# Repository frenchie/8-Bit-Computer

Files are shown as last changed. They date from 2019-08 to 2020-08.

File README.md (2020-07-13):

# An 8-bit Computer

My take on breadboard computer designs from [Ben Eater](https://eater.net/8bit) ([YouTube](https://www.youtube.com/channel/UCS0N5baNlQWJCUrhCEo8WlA)) and [James Bates](https://github.com/jamesbates/jcpu) ([YouTube](https://www.youtube.com/channel/UCH09NwwJsfThwLKvc6kxl4Q)).

## Licensing

* The AVR Code for the 7-segment display driver, ALU & Clock are available to use under a MIT license
* The Microcode generator & associated tools are available to use under a MIT license
* All KiCAD design files are licensed Creative Commons Attribution-ShareAlike 4.0 International (CC BY-SA 4.0)
* The AVR In-System Programmer AVR includes Peter Fluery's i2c library and is licensed under the GPLv3
* The Included AVR Makefiles are Public Domain.

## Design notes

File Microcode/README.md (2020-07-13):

microcode.bin is the latest compiled microcode for the included c file.

If you wish to generate it yourself, compile microcode.c (cc -o microcode microcode.c) then run microcode.

The tools folder contains useful scripts to use on a Raspberry Pi

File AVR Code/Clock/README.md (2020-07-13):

This code works on a variety of 8-pin ATtiny devices. You can use an ATtiny25, 45, 85 or an ATtiny13. Make sure you modify the Makefile to match the device you are using.

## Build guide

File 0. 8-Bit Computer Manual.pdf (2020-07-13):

# Hardware Overview:

RAM:

The main system RAM is a 64Kbit 6264 CMOS static RAM which is divided into 8,192 8-bit words. To simplify the hardware design memory access is limited to 512 bytes (9 bits). This is further subdivided into 256 bytes of program memory which can be set with the hardware DIP switches and 256 bytes of data memory which can be read and modified by a running program.

To set the program memory push the PROGRAM button located adjacent to the right DIP switches. The status LED adjacent the left DIP switches will illuminate RED. The ram address (orange LEDs) will be mapped to the left DIP switches and the currently programmed value will be shown on the data LEDs (green). While in program mode, when the LOAD button is pushed, the value on the right DIP switches will be copied into RAM.

To exit program mode, push the PROGRAM button. The status LED will illuminate GREEN. The LOAD button and dip switches do nothing while in run mode. In run mode, the address is set by the Memory Address Register (chip to the left of the memory LEDs). This register is not accessed directly and is instead set as required by the various operations.

The DATA MEM status LED will illuminate whenever a program is accessing data memory.

Clock:

The main system clock can be driven automatically or manually. The AUTO/MAN button toggles between the two modes and the adjacent LEDs will indicate green for Automatic, or red for Manual.

In automatic mode, the clock will pulse at a frequency of 1 Hz to 60 Hz, depending on the position of the potentiometer. In manual mode, the clock will pulse once every time the CLOCK ADV button is pushed.

If the computer is halted (red HALT LED lit), the clock will not advance in manual or automatic mode. A RESET will be required to release the system from halt.

Program Counter:

The program counter keeps track of the next command to run in the program. It increments automatically once its contained value is transferred to the memory address register. Jump operations are completed by loading a value into the program counter and overriding the current count.

Step Counter:

Every operation takes multiple clock cycles to complete (minimum 3). The step counter tracks the current progress through the operation and increments on a clock falling edge. The counter will reset to zero whenever the micro step reset (MSR) signal is active and the clock goes low.

Eg. The signals in a MOV A, B operation are:

0: Program Counter OUT, Memory Address Register IN
1: RAM OUT, Instruction Register IN, Program Counter ENABLE 2: B OUT, A IN, Micro Step Reset

Note that steps 0 and 1 are the same in all operations.

Reset:

The RESET signal sets the Program Counter and Step Counter Values to 0 and starts operation at the beginning of the loaded program.

Register and Memory contents are not erased.

Instruction Register:

The instruction register latches the currently executing operation to the control ROM, freeing the memory to conduct other tasks. It always latches the memory contents on Step 1.

Microcode ROM:

The Microcode ROMs are comprised of 3x 64kbit (8K) parallel EEPROMs. The 13 address lines of the ROMs are driven in parallel, with 8 bits coming from the instruction register, 3 bits coming from the step counter and the remaining two bits originating from the ALU flags register.

Microcode is written to the board by writing to a 32KB I²C EEPROM using a raspberry pi and a 3.3V (pi) to 5V (board) level shifter. The EEPROM can be added as a block device in Linux using the 24C256 kernel driver and then written or read directly with dd(1). A full read of the EEPROM takes around 3 seconds. A full write takes around 30 seconds. To limit re-writes of unchanged data a python flashing script first dumps the contents of the EEPROM and then compares with the new bin file and flashes only the changed bytes.

At board power on a dedicated ATMega16 microcontroller reads byte 32,768 of the I²C EEPROM. If it finds a non-zero value, it checks the contents of each of the 3 parallel 8K EEPROMS in turn and updates any changed values. Read times on the parallel EEPROMS are in the order of 100ns. Write times are in the order of 10ms per byte. A full read takes around 3 seconds. A full write takes ~ 5 minutes. At the conclusion of the check, the microcontroller writes a zero to byte 32,768 and then shuts down.

Each microcode ROM drives 8 control signals for a total of 24. Any signal denoted with a bar on the schematic ie: AO´ is an active low signal.

AI | A register IN
AO | A register OUT
BI | B register IN
BO | B register OUT
CI | C register IN
CO | C register OUT
DI | D register IN
DO | D register OUT
ΣI | ALU IN
ΣO | ALU OUT
Σ0 | ALU Command Bit 0
Σ1 | ALU Command Bit 1
Σ2 | ALU Command Bit 2
Σ3 | ALU Command Bit 3
MP | Program Memory / Data Memory Select (H/L)
MI | Memory Address Register In
RI | RAM Data IN
RO | RAM Data OUT
PI | Program Counter IN
PO | Program Counter OUT
PE | Program Counter ENABLE (count on next clock pulse)
HLT | Halt
IRI | Instruction Register IN
MSR | Micro Step Reset
RESET | Reset the Program Counter & Step Counter to 0 Note: This is user generated by a push button.

Arithmetic Logic Unit (ALU):

The ALU is built around an Atmel ATMega16 AVR microcontroller as most discrete ALU logic chips have been obsolete for 10-20 years and old stock is expensive. The microcontroller has 32 I/O lines which are split as following:
- 8 bits Input (ALU Input Register)
- 8 bits Input (Connected to the B Register)
- 4 bits Input (ALU Command Select)
- 8 bits Output (ALU Result)
- 4 bits Output (Flags Register)

In the spirit of the project, the ALU is largely programmed to be compatible with a 74LS382 TTL ALU with a few additional operations that could easily be implemented in logic – ie no multiplications, no division.

The ALU sets four flags on the result of a calculation which are used for conditional jumps.

Flags:

Flag | Description
Carry | The result overflowed from 255 to 0 or underflowed from 0 to 255.
Overflow | The result overflowed from 127 to -128 or underflowed from -128 to 127
Negative | The result is negative (ie >128 unsigned)
Zero | The result is zero

Registers:

The computer has four registers. Note that Register D serves double duty as the stack pointer, if it is overwritten the current stack position will be lost unless copied elsewhere and recovered.

Register | Address | Special Function
A | 000 | Decimal Display
B | 001 | ALU B Input
C | 010 | None
D | 011 | Stack Pointer

Special Addresses:

Item | Address | Description
SP | 100 | Stack Pointer (Alias of Register D). Note: This would be used for Register E if there were enough control signals to add another register without adding a fourth ROM.
PC | 101 | Program Counter
SPi | 110 | Stack Pointer Increment (Used in PUSH/POP operations to INC/DEC the SP).
IMM | 111 | Immediate memory access, loads a value from the next byte of program memory.

Decimal Display:

Register A is equipped with a 4-digit, 7-segment display. The adjacent dip switch can be used to select the output mode.

Switches | Description
00 | Display outputs in unsigned decimal
01 | Display outputs in signed decimal. The last decimal place is illuminated.
10 | Display outputs in hexadecimal. Display is prefixed with a H
11 | Display outputs in binary

# Instruction Set:

Note, all undefined operations will result in a clock halt.

Move Class Operations (00 XXX YYY)

Operation | Opcode | Description | Notes
MOV X, Y | 00 XXX YYY | Copy the contents of register Y into register X | X & Y from the register table. Moving a register to itself will cause a halt except for the NOP instruction below.
MOV X, IMM | 00 XXX 111 | Copy the next byte of memory into register X | X from the register table.
NOP | 00 000 000 | No operation | Implemented as MOV A, A
HLT | 00 101 101 | Halt the clock (reset counters to release) | Implemented as MOV PC, PC
JMP | 00 101 111 | Jump to address stored in next byte of memory | Implemented as MOV PC, IMM
JC | 00 111 000 | Jump to address stored in next byte of memory when the CARRY flag is set | Implemented as MOV IMM, Flags The 3 least significant bits are decoded in hardware
JZ | 00 111 001 | Jump to address stored in next byte of memory when the ZERO flag is set | Implemented as MOV IMM, Flags The 3 least significant bits are decoded in hardware
JN | 00 111 010 | Jump to address stored in next byte of memory when the NEGATIVE flag is set | Implemented as MOV IMM, Flags The 3 least significant bits are decoded in hardware
JO | 00 111 100 | Jump to address stored in next byte of memory when the OVERFLOW flag is set | Implemented as MOV IMM, Flags The 3 least significant bits are decoded in hardware

## Data Memory Operations:

Unless otherwise specified, all operations listed in this section act on the 256-byte data memory.

Load Class Operations (01 XXX YYY)

Operation | Opcode | Description | Notes
LOD X, [Y] | 01 XXX YYY | Copies memory located at address held in register Y into register X.
LOD X, IMM | 01 XXX 111 | Copies memory at address held in the next byte of program memory into register X.
POP X | 01 XXX 110 | Decrements the stack pointer, copies memory at the new stack pointer address into register X.

Store Class Operations (10 XXX YYY)

Operation | Opcode | Description | Notes
STO [X], Y | 10 XXX YYY | Copies data in register Y into memory address held in register X
STO IMM, Y | 10 111 YYY | Copies data in register Y into memory at address held in the next byte of program memory.
PUSH Y | 10 110 YYY | Copies data in register Y into the address held in the stack pointer & increments the stack pointer.

## ALU:

ALU Operations (11 ΣΣΣΣ XX):
All ALU operations take a command and a single register which acts as the “A” input. The supplied register is updated with the result from the calculation ie: X = ALU(Σ, X). The ALU requires 4 bits to set the desired calculation, the remaining two bits are the least significant bits of the A, B, C or D register. As a result, the ALU is not able to operate on the program counter directly.

The slightly unusual ordering of the four command bits is because the ALU microcontroller is programmed to be bit-compatible with the (very) obsolete 74LS382 ALU chip which defines the order of the first 8 commands.

Single operand commands

Operation | Opcode | Description | Notes
LST X | 11 0000 XX | Copies the last ALU result into register X | This is required to latch the ALU result. The four ALU command signals are only active for one microstep of an ALU operation and are 0000 at all other times.
ZER X | 11 1000 XX | Copies 0 into register X | Used heavily for initialising registers
NOT X | 11 1001 XX | Bitwise NOT | ~X
INC X | 11 1010 XX | Increment X | X + 1
DEC X | 11 1011 XX | Decrement X | X - 1
RET X | 11 0111 XX | Returns X | Lets the ALU be used a temporary register. Note: This isn’t that useful and may be changed to a test for equality operation in a future microcode update.

Some ALU operations require a second input which is supplied by the B register (hardwired to the ALU). The B Register can also be used as the A input. Ie ZER B, and XOR B are functionally equivalent operations.

Operation | Opcode | Description | Notes
SBX X | 11 0001 XX | Subtract X from the B Register | B - X
SUB X | 11 0010 XX | Subtract B from the X Register | X - B
SBC X | 11 1111 XX | Subtract B from the X Register, with carry | X - B - 1
ADD X | 11 0011 XX | Add B to the X Register | X + B
ADC X | 11 1110 XX | Add B to the X Register, with carry | X + B + 1
XOR X | 11 0100 XX | Bitwise XOR | X ^ B
OR X | 11 0101 XX | Bitwise OR | X | B
AND X | 11 0110 XX | Bitwise AND | X & B
LSH X | 11 1100 XX | Left shift | X << B
RSH X | 11 1101 XX | Right shift | X >> B

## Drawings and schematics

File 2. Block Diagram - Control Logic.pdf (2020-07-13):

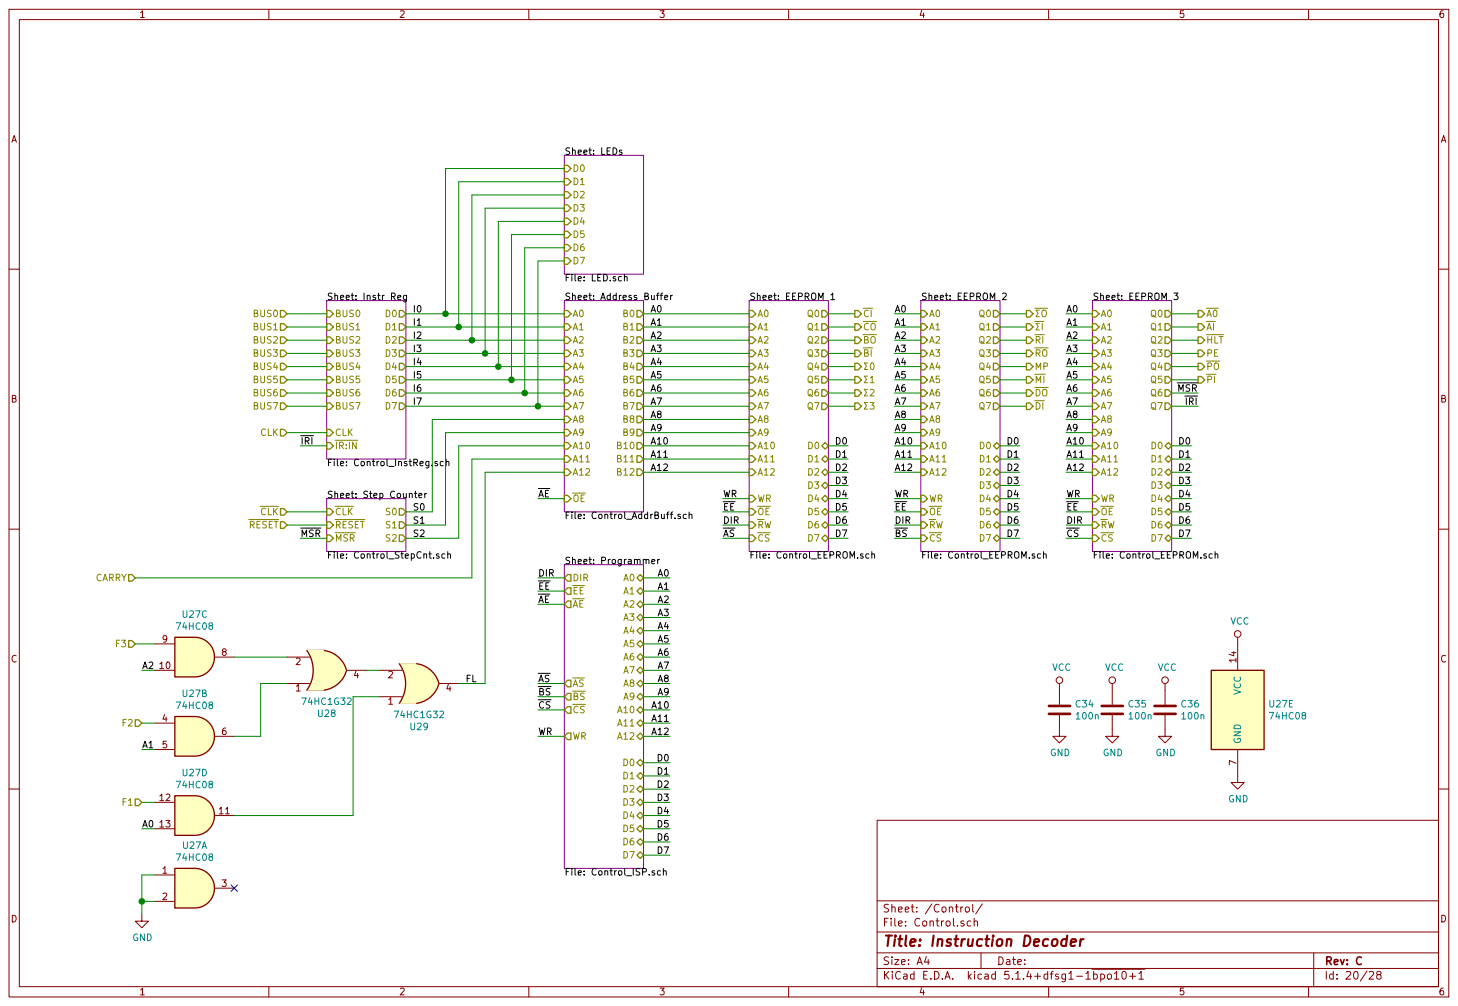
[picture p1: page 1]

Sheet: LEDs File: LED.sch D2 D3 D0 D1 D6 D7 D4 D5

I1
I2
I3
I4
I5
I6
I7

Sheet: Programmer File: Control_ISP.sch A0A1A2A3A4A5A6A7 A12 A11 A10A9A8D7 D6 D5 D4 D3 D2 D1 D0 DIR

Id: 20/28 Title: Instruction Decoder File: Control.sch Sheet: /Control/

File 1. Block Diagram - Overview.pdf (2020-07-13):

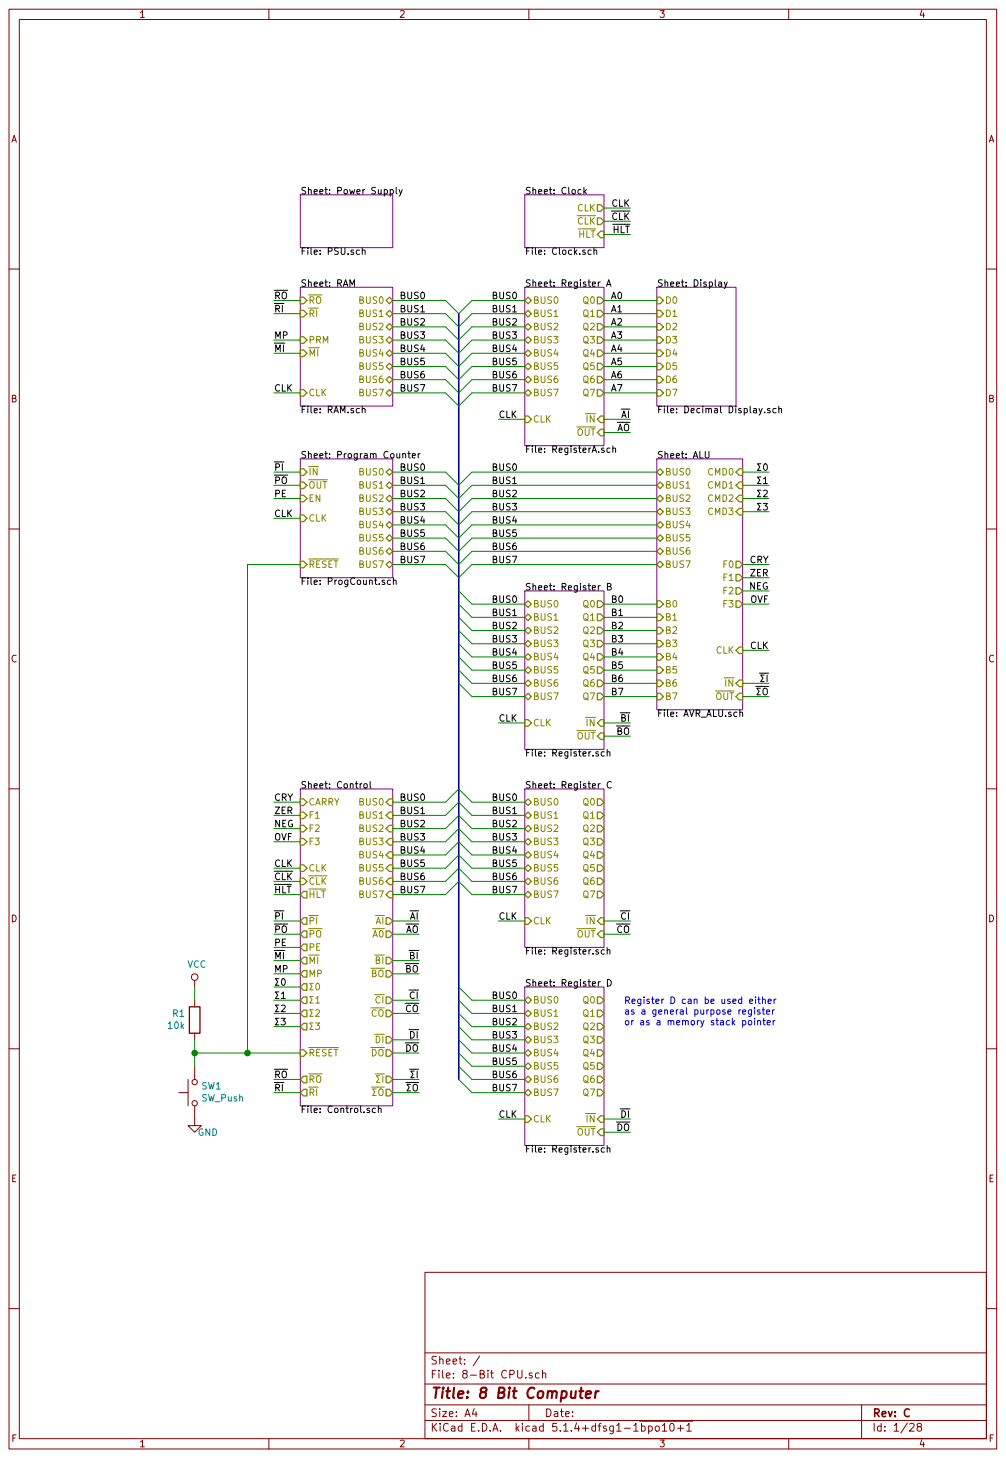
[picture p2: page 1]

B1B0 Sheet: Register A
CLK MI R1
File: ProgCount.sch OUT CLK

Sheet: Power Supply File: PSU.sch

File: Decimal Display.sch D0 D1 D2 D3 D7 D6 D5 D4 Sheet: Clock File: Clock.schCLK CLK HLT Sheet: Program Counter

Sheet: RAM
I3 BUS0 BUS0 BUS1 BUS2 BUS3 BUS4 BUS5 BUS6 BUS7 CLK
File: RAM.sch BUS0 BUS1 BUS2 BUS3 BUS4 BUS5 BUS6 BUS7 RO

as a general purpose register
or as a memory stack pointer

Id: 1/28 Title: 8 Bit Computer File: 8-Bit CPU.sch Sheet: /

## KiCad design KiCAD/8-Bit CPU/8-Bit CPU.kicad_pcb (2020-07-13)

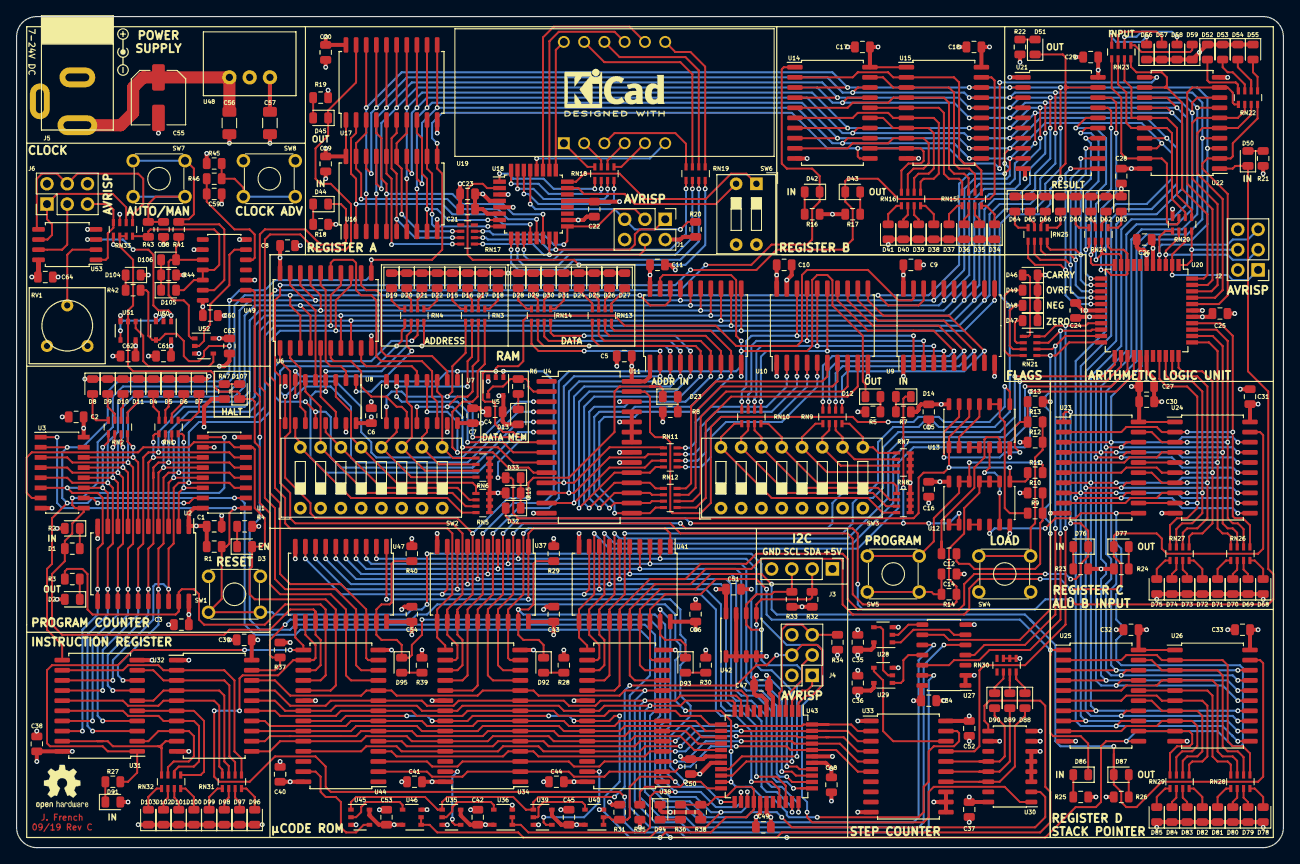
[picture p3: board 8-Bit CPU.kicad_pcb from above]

Board: 4 copper layers, 158.8 x 104.1 mm, 320 parts (0 on the bottom side), 375 nets.

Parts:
C1, C2, C3, C4, C5, C6, C7, C8, C9, C10, C11, C15, C16, C17, C18, C19, C20, C21, C22, C23, C24, C25, C26, C27, C28, C29, C30, C31, C32, C33, C34, C35, C36, C37, C38, C39, C40, C41, C42, C43, C44, C45, C46, C47, C48, C49, C50, C51, C52, C53, C54, C60, C61, C62, C63, C64: 100n; C_0805_2012Metric
C12, C13, C59: 1u; C_0805_2012Metric
C14, C58: 47n; C_0805_2012Metric
C55: 100u; C_Elec_6.3x7.7
C56: 10u; C_1206_3216Metric
C57: 22u; C_1206_3216Metric
D1, D2, D3, D4, D5, D6, D7, D8, D9, D10, D11, D12, D13, D14, D15, D16, D17, D18, D19, D20, D21, D22, D23, D24, D25, D26, D27, D28, D29, D30, D31, D34, D35, D36, D37, D38, D39, D40, D41, D42, D43, D44, D45, D46, D47, D48, D49, D50, D51, D52, D53, D54, D55, D56, D57, D58, D59, D60, D61, D62, D63, D64, D65, D66, D67, D68, D69, D70, D71, D72, D73, D74, D75, D76, D77, D78, D79, D80, D81, D82, D83, D84, D85, D86, D87, D88, D89, D90, D91, D92, D93, D94, D95, D96, D97, D98, D99, D100, D101, D102, D103: LED; LED_0805_2012Metric
D32, D104, D105: GREEN; LED_0805_2012Metric
D33, D106, D107: RED; LED_0805_2012Metric
J1, J2, J4, J6: AVRISP; PinHeader_2x03_P2.54mm_Vertical
J3: I2C; PinHeader_1x04_P2.54mm_Vertical
J5: 7-20V; PJ-202A
R1, R9, R12, R13, R20, R29, R31, R34, R35, R37, R38, R40, R45, R46: 10k; R_0805_2012Metric
R2, R3, R4, R5, R7, R8, R11, R15, R16, R17, R18, R19, R21, R22, R23, R24, R25, R26, R27, R28, R30, R36, R39, R41, R42, R44, R47: 1k; R_0805_2012Metric
R6: 390; R_0805_2012Metric
R10: 4k7; R_0805_2012Metric
R14, R43: 220k; R_0805_2012Metric
R32, R33: 3k3; R_0805_2012Metric
RN1, RN2, RN3, RN4, RN13, RN14, RN15, RN16, RN21, RN22, RN23, RN24, RN25, RN26, RN27, RN28, RN29, RN30, RN31, RN32: 1k; R_Array_Concave_4x0603
RN5, RN6, RN7, RN8, RN9, RN10, RN11, RN12, RN17, RN33: 10k; R_Array_Concave_4x0603
RN18, RN19: 680R; R_Array_Concave_4x0603
RN20: 4k7; R_Array_Concave_4x0603
RV1: 50k; BOURNS-3310Y
SW1, SW4, SW5: SW_Push; SW_TH_Tactile_Omron_B3F-10xx_Fixed
SW2, SW3: SW_DIP_x08; SW_DIP_SPSTx08_Slide_9.78x22.5mm_W7.62mm_P2.54mm
SW6: SW_DIP_x02; SW_DIP_SPSTx02_Slide_9.78x7.26mm_W7.62mm_P2.54mm
SW7: MODE; SW_TH_Tactile_Omron_B3F-10xx_Fixed
SW8: CLK; SW_TH_Tactile_Omron_B3F-10xx_Fixed
U1, U3, U30: 74HC161; SOIC-16_3.9x9.9mm_P1.27mm
U2, U15, U17, U21, U24, U26: 74HC245; SOIC-20W_7.5x12.8mm_P1.27mm_Rounded
U4: 6264SL; SOIC-28W-LY6264
U5, U28, U29, U50: 74HC1G32; TSOP-5_1.65x3.05mm_P0.95mm
U6, U14, U16, U22, U23, U25: 74HC377; SOIC-20W_7.5x12.8mm_P1.27mm_Rounded
U7, U8: 74HC157; SOIC-16_3.9x9.9mm_P1.27mm_JCF
U9, U10, U11, U32, U33, U37, U41, U47: 74HC245; SOIC-20W_7.5x12.8mm_P1.27mm
U12: 74HC00; SOIC-14_3.9x8.7mm_P1.27mm_JCF
U13: 74HC132; SOIC-14_3.9x8.7mm_P1.27mm_JCF
U18: ATmega48-20AU; TQFP-32_7x7mm_P0.8mm
U19: FJ4401AG
U20, U43: ATmega16-16AU; TQFP-44_10x10mm_P0.8mm
U27: 74HC08; SOIC-14_3.9x8.7mm_P1.27mm_JCF
U31: 74HC377; SOIC-20W_7.5x12.8mm_P1.27mm
U34, U38, U44: 28C64B; SOIC-28W_7.5x17.9mm_P1.27mm
U35, U36, U39, U40, U45, U46: 74HC1G00; TSOP-5_1.65x3.05mm_P0.95mm
U42: CAT24C256; SOIC-8_3.9x4.9mm_P1.27mm
U48: K7805M-1000R3; K78xxM-1000R3
U49: 74HC14; SOIC-14_3.9x8.7mm_P1.27mm_JCF
U51, U52: 74HC1G08; TSOP-5_1.65x3.05mm_P0.95mm
U53: ATtiny45-20SU; SOIC-8_5.275x5.275mm_P1.27mm
svg2mod: G***; Polarity_marking_center_positive_1.5mm_FrontS

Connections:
+12V: C55.1, C56.1, J5.1, U48.1
/A0: U16.2, U17.2, U18.12
/A1: U16.19, U17.3, U18.13
/A2: U16.5, U17.4, U18.14
/A3: RN17.4, U16.16, U17.5
/A4: RN17.3, U16.6, U17.6
/A5: RN17.2, U16.15, U17.7
/A6: U16.9, U17.8, U18.7
/A7: U16.12, U17.9, U18.8
/ALU/B0: RN22.8, U20.40, U22.2
/ALU/B1: RN22.7, U20.41, U22.5
/ALU/B2: RN22.6, U20.42, U22.6
/ALU/B3: RN22.5, U20.43, U22.9
/ALU/B4: RN23.8, U20.44, U22.12
/ALU/B5: RN20.1, RN23.7, U22.15
/ALU/B6: RN20.2, RN23.6, U22.16
/ALU/B7: RN20.3, RN23.5, U22.19
/ALU/PB5:MOSI: J2.4, RN20.8, U20.1
/ALU/PB6:MISO: J2.1, RN20.7, U20.2
/ALU/PB7:SCK: J2.3, RN20.6, U20.3
/ALU/PD0: RN24.8, U20.9, U21.18
/ALU/PD1: RN24.7, U20.10, U21.17
/ALU/PD2: RN24.6, U20.11, U21.16
/ALU/PD3: RN24.5, U20.12, U21.15
/ALU/PD4: RN25.8, U20.13, U21.14
/ALU/PD5: RN25.7, U20.14, U21.13
/ALU/PD6: RN25.6, U20.15, U21.12
/ALU/PD7: RN25.5, U20.16, U21.11
/ALU/~RESET: J2.5, RN20.5, U20.4
/BUS0: U1.3, U2.18, U6.13, U9.11, U11.11, U14.3, U15.18, U16.3, U17.18, U21.2, U22.3, U23.3, U24.18, U25.3, U26.18, U31.13
/BUS1: U1.4, U2.17, U6.14, U9.12, U11.12, U14.18, U15.17, U16.18, U17.17, U21.3, U22.4, U23.18, U24.17, U25.18, U26.17, U31.8
/BUS2: U1.5, U2.16, U6.8, U9.13, U11.13, U14.4, U15.16, U16.4, U17.16, U21.4, U22.7, U23.4, U24.16, U25.4, U26.16, U31.7
/BUS3: U1.6, U2.15, U6.7, U9.14, U11.14, U14.17, U15.15, U16.17, U17.15, U21.5, U22.8, U23.17, U24.15, U25.17, U26.15, U31.14
/BUS4: U2.14, U3.3, U6.17, U9.15, U11.15, U14.7, U15.14, U16.7, U17.14, U21.6, U22.13, U23.7, U24.14, U25.7, U26.14, U31.4
/BUS5: U2.13, U3.4, U6.4, U9.16, U11.16, U14.14, U15.13, U16.14, U17.13, U21.7, U22.14, U23.14, U24.13, U25.14, U26.13, U31.17
/BUS6: U2.12, U3.5, U6.18, U9.17, U11.17, U14.8, U15.12, U16.8, U17.12, U21.8, U22.17, U23.8, U24.12, U25.8, U26.12, U31.3
/BUS7: U2.11, U3.6, U6.3, U9.18, U11.18, U14.13, U15.11, U16.13, U17.11, U21.9, U22.18, U23.13, U24.11, U25.13, U26.11, U31.18
/C0: RN26.5, U20.37, U23.2, U24.2
/C1: RN26.6, U20.36, U23.19, U24.3
/C2: RN26.7, U20.35, U23.5, U24.4
/C3: RN26.8, U20.34, U23.16, U24.5
/C4: RN27.5, U20.33, U23.6, U24.6
/C5: RN27.6, U20.32, U23.15, U24.7
/C6: RN27.7, U20.31, U23.9, U24.8
/C7: RN27.8, U20.30, U23.12, U24.9
/CLK: R42.2, U1.2, U3.2, U6.11, U12.5, U14.11, U16.11, U22.11, U23.11, U25.11, U31.11, U49.1, U50.4
/CRY: RN21.8, U20.19, U33.17
/Clock/AVR: D105.2, R43.2, RN33.4, U49.11, U49.12
/Clock/AVR Clock/CLK: U50.1, U53.3
/Clock/AVR Clock/MISO: J6.1, RN33.6, U53.6
/Clock/AVR Clock/MOSI: J6.4, RN33.5, U53.5
/Clock/AVR Clock/SCK: J6.3, U53.7
/Clock/AVR Clock/~RESET: J6.5, RN33.8, U53.1
/Clock/MAN: D106.2, R41.1, U49.10, U52.1
/Control/A0: U27.13, U32.18, U34.10, U38.10, U43.9, U44.10
/Control/A1: U27.5, U32.17, U34.9, U38.9, U43.10, U44.9
/Control/A2: U27.10, U32.16, U34.21, U38.21, U43.11, U44.21
/Control/A3: U32.15, U34.8, U38.8, U43.12, U44.8
/Control/A4: U32.14, U34.7, U38.7, U43.13, U44.7
/Control/A5: U32.13, U34.23, U38.23, U43.14, U44.23
/Control/A6: U32.12, U34.6, U38.6, U43.15, U44.6
/Control/A7: U32.11, U34.24, U38.24, U43.16, U44.24
/Control/A8: U33.6, U34.2, U38.2, U43.40, U44.2
/Control/A9: U33.5, U34.3, U38.3, U43.41, U44.3
/Control/A10: U33.4, U34.4, U38.4, U43.42, U44.4
/Control/A11: U33.3, U34.25, U38.25, U43.43, U44.25
/Control/A12: U33.2, U34.5, U38.5, U43.44, U44.5
/Control/D0: U37.2, U41.2, U43.37, U47.2
/Control/D1: U37.3, U41.3, U43.36, U47.3
/Control/D2: U37.4, U41.4, U43.35, U47.4
/Control/D3: U37.5, U41.5, U43.34, U47.5
/Control/D4: U37.6, U41.6, U43.33, U47.6
/Control/D5: U37.7, U41.7, U43.32, U47.7
/Control/D6: U37.8, U41.8, U43.31, U47.8
/Control/D7: U37.9, U41.9, U43.30, U47.9
/Control/DIR: R35.2, U37.1, U41.1, U43.22, U47.1
/Control/EEPROM 1/~WR: U38.27, U39.4
/Control/EEPROM 2/~WR: U34.27, U35.4
/Control/EEPROM 3/~WR: U44.27, U45.4
/Control/FL: U29.4, U33.18
/Control/I0: RN31.5, U31.12, U32.2
/Control/I1: RN31.6, U31.9, U32.3
/Control/I2: RN31.7, U31.6, U32.4
/Control/I3: RN31.8, U31.15, U32.5
/Control/I4: RN32.5, U31.5, U32.6
/Control/I5: RN32.6, U31.16, U32.7
/Control/I6: RN32.7, U31.2, U32.8
/Control/I7: RN32.8, U31.19, U32.9
/Control/Programmer/MISO: J4.1, U43.2
/Control/Programmer/SCK: J4.3, U43.3
/Control/Programmer/SCL: J3.3, R33.1, U42.6, U43.19
/Control/Programmer/SDA: J3.2, R32.1, U42.5, U43.20
/Control/Programmer/~RST: J4.5, R34.2, U43.4
/Control/S0: D88.2, U30.14, U33.14
/Control/S1: D89.2, U30.13, U33.15
/Control/S2: D90.2, U30.12, U33.16
/Control/WR: J4.4, U35.1, U39.1, U43.1, U45.1
/Control/~AE: R37.1, U32.19, U33.19, U43.21
/Control/~AS: D93.1, R31.2, U40.1, U40.2, U41.19, U43.23
/Control/~BS: D92.1, R29.2, U36.1, U36.2, U37.19, U43.24
/Control/~CS: D95.1, R40.2, U43.25, U46.1, U46.2, U47.19
/Control/~EE: R36.2, R38.1, U34.22, U38.22, U43.26, U44.22
/Control/~IRI: R27.1, U31.1, U44.15, U47.11
/Control/~MSR: U30.9, U44.16, U47.12
/Control/~RESET: R1.1, SW1.2, U1.1, U3.1, U30.1
/Display/CC1: U18.25, U19.12
/Display/CC2: U18.26, U19.9
/Display/CC3: U18.27, U19.8
/Display/CC4: U18.28, U19.6
/Display/CMD0: SW6.2, U18.23
/Display/CMD1: SW6.1, U18.24
/Display/DP: RN19.4, U19.3
/Display/PB3:MOSI: J1.4, RN17.5, U18.15
/Display/PB4:MISO: J1.1, RN17.6, U18.16
/Display/PB5:SCK: J1.3, RN17.7, U18.17
/Display/PD0: RN18.4, U18.30
/Display/PD1: RN18.3, U18.31
/Display/PD2: RN18.2, U18.32
/Display/PD3: RN18.1, U18.1
/Display/PD4: RN19.8, U18.2
/Display/PD5: RN19.7, U18.9
/Display/PD6: RN19.6, U18.10
/Display/PD7: RN19.5, U18.11
/Display/a: RN19.3, U19.11
/Display/b: RN19.1, U19.7
/Display/c: RN18.6, U19.4
/Display/d: RN18.7, U19.2
/Display/e: RN18.8, U19.1
/Display/f: RN19.2, U19.10
/Display/g: RN18.5, U19.5
/Display/~RESET: J1.5, R20.2, U18.29
/MP: U5.1, U34.18, U37.14
/NEG: RN21.6, U20.21, U27.4
/OVF: RN21.5, U20.22, U27.9
/PE: D3.2, U1.7, U3.7, U44.19, U47.15
/Program Counter/PC0: RN1.8, U1.14, U2.2
/Program Counter/PC1: RN1.7, U1.13, U2.3
/Program Counter/PC2: RN1.6, U1.12, U2.4
/Program Counter/PC3: RN1.5, U1.11, U2.5
/Program Counter/PC4: RN2.8, U2.6, U3.14
/Program Counter/PC5: RN2.7, U2.7, U3.13
/Program Counter/PC6: RN2.6, U2.8, U3.12
/Program Counter/PC7: RN2.5, U2.9, U3.11
/Program Counter/PCC: U1.15, U3.10
/RAM/AddrReg/D0A: U6.12, U7.2
/RAM/AddrReg/D0B: RN6.5, SW2.9, U7.3
/RAM/AddrReg/D1A: U6.15, U7.14
/RAM/AddrReg/D1B: RN6.6, SW2.10, U7.13
/RAM/AddrReg/D2A: U6.9, U7.5
/RAM/AddrReg/D2B: RN6.7, SW2.11, U7.6
/RAM/AddrReg/D3A: U6.6, U7.11
/RAM/AddrReg/D3B: RN6.8, SW2.12, U7.10
/RAM/AddrReg/D4A: U6.16, U8.2
/RAM/AddrReg/D4B: RN5.5, SW2.13, U8.3
/RAM/AddrReg/D5A: U6.5, U8.14
/RAM/AddrReg/D5B: RN5.6, SW2.14, U8.13
/RAM/AddrReg/D6A: U6.19, U8.5
/RAM/AddrReg/D6B: RN5.7, SW2.15, U8.6
/RAM/AddrReg/D7A: U6.2, U8.11
/RAM/AddrReg/D7B: RN5.8, SW2.16, U8.10
/RAM/Data IO/D0: RN12.5, U10.9
/RAM/Data IO/D0A: RN9.1, U9.9, U10.11
/RAM/Data IO/D0B: RN7.1, RN9.8, SW3.9
/RAM/Data IO/D1: RN12.6, U10.8
/RAM/Data IO/D1A: RN9.2, U9.8, U10.12
/RAM/Data IO/D1B: RN7.2, RN9.7, SW3.10
/RAM/Data IO/D2: RN12.7, U10.7
/RAM/Data IO/D2A: RN9.3, U9.7, U10.13
/RAM/Data IO/D2B: RN7.3, RN9.6, SW3.11
/RAM/Data IO/D3: RN12.8, U10.6
/RAM/Data IO/D3A: RN9.4, U9.6, U10.14
/RAM/Data IO/D3B: RN7.4, RN9.5, SW3.12
/RAM/Data IO/D4: RN11.5, U10.5
/RAM/Data IO/D4A: RN10.1, U9.5, U10.15
/RAM/Data IO/D4B: RN8.1, RN10.8, SW3.13
/RAM/Data IO/D5: RN11.6, U10.4
/RAM/Data IO/D5A: RN10.2, U9.4, U10.16
/RAM/Data IO/D5B: RN8.2, RN10.7, SW3.14
/RAM/Data IO/D6: RN11.7, U10.3
/RAM/Data IO/D6A: RN10.3, U9.3, U10.17
/RAM/Data IO/D6B: RN8.3, RN10.6, SW3.15
/RAM/Data IO/D7: RN11.8, U10.2
/RAM/Data IO/D7A: RN10.4, U9.2, U10.18
/RAM/Data IO/D7B: RN8.4, RN10.5, SW3.16
/RAM/MA0: RN3.8, U4.10, U7.4
/RAM/MA1: RN3.7, U4.9, U7.12
/RAM/MA2: RN3.6, U4.8, U7.7
/RAM/MA3: RN3.5, U4.7, U7.9
/RAM/MA4: RN4.8, U4.6, U8.4
/RAM/MA5: RN4.7, U4.5, U8.12
/RAM/MA6: RN4.6, U4.4, U8.7
/RAM/MA7: RN4.5, U4.3, U8.9
/RAM/MAN: D33.2, R11.1, U5.2, U7.1, U8.1, U9.19, U12.8, U13.1, U13.12
/RAM/RAM0: RN12.4, RN13.8, U4.15, U11.9
/RAM/RAM1: RN12.3, RN13.7, U4.16, U11.8
/RAM/RAM2: RN12.2, RN13.6, U4.17, U11.7
/RAM/RAM3: RN12.1, RN13.5, U4.18, U11.6
/RAM/RAM4: RN11.4, RN14.8, U4.19, U11.5
/RAM/RAM5: RN11.3, RN14.7, U4.13, U11.4
/RAM/RAM6: RN11.2, RN14.6, U4.12, U11.3
/RAM/RAM7: RN11.1, RN14.5, U4.11, U11.2
/RAM/~WR: U4.27, U13.8
/Register B/Q0: RN15.5, U14.2, U15.2
/Register B/Q1: RN15.6, U14.19, U15.3
/Register B/Q2: RN15.7, U14.5, U15.4
/Register B/Q3: RN15.8, U14.16, U15.5
/Register B/Q4: RN16.5, U14.6, U15.6
/Register B/Q5: RN16.6, U14.15, U15.7
/Register B/Q6: RN16.7, U14.9, U15.8
/Register B/Q7: RN16.8, U14.12, U15.9
/Stack Pointer/Q0: RN28.5, U25.2, U26.2
/Stack Pointer/Q1: RN28.6, U25.19, U26.3
/Stack Pointer/Q2: RN28.7, U25.5, U26.4
/Stack Pointer/Q3: RN28.8, U25.16, U26.5
/Stack Pointer/Q4: RN29.5, U25.6, U26.6
/Stack Pointer/Q5: RN29.6, U25.15, U26.7
/Stack Pointer/Q6: RN29.7, U25.9, U26.8
/Stack Pointer/Q7: RN29.8, U25.12, U26.9
/ZER: RN21.7, U20.20, U27.12
/~AI: D44.1, U16.1, U44.12, U47.17
/~AO: D45.1, U17.19, U44.13, U47.18
/~BI: D42.1, U14.1, U34.15, U37.11
/~BO: D43.1, U15.19, U34.16, U37.12
/~CI: D76.1, U23.1, U38.19, U41.15
/~CLK: U30.2, U49.2
/~CO: D77.1, U24.19, U38.11, U41.16
/~HLT: D107.1, RN33.2, RN33.3, U44.11, U47.16, U51.2
/~MI: D23.1, U6.1, U34.17, U37.13
/~PI: R2.1, U1.9, U3.9, U44.17, U47.13
/~PO: R3.1, U2.19, U44.18, U47.14
/~RI: D14.1, U12.1, U12.2, U34.11, U37.16
/~RO: D12.1, U11.19, U34.19, U37.15
/~SPI: D86.1, U25.1, U38.13, U41.18
/~SPO: D87.1, U26.19, U38.12, U41.17
/~ΣI: D50.1, U22.1, U34.12, U37.17
/~ΣO: D51.1, U21.19, U34.13, U37.18
/Σ0: U20.23, U38.18, U41.14
/Σ1: U20.24, U38.17, U41.13
/Σ2: U20.25, U38.16, U41.12
/Σ3: U20.26, U38.15, U41.11
GND: C1.2, C2.2, C3.2, C4.2, C5.2, C6.2, C7.2, C8.2, C9.2, C10.2, C11.2, C13.2, C14.2, C15.2, C16.2, C17.2, C18.2, C19.2, C20.2, C21.2, C22.2, C23.2, C24.2, C25.2, C26.2, C27.2, C28.2, C29.2, C30.2, C31.2, C32.2, C33.2, C34.2, C35.2, C36.2, C37.2, C38.2, C39.2, C40.2, C41.2, C42.2, C43.2, C44.2, C45.2, C46.2, C47.2, C48.2, C49.2, C50.2, C51.2, C52.2, C53.2, C54.2, C55.2, C56.2, C57.2, C58.2, C59.2, C60.2, C61.2, C62.2, C63.2, C64.2, D4.1, D5.1, D6.1, D7.1, D8.1, D9.1, D10.1, D11.1, D15.1, D16.1, D17.1, D18.1, D19.1, D20.1, D21.1, D22.1, D24.1, D25.1, D26.1, D27.1, D28.1, D29.1, D30.1, D31.1, D34.1, D35.1, D36.1, D37.1, D38.1, D39.1, D40.1, D41.1, D46.1, D47.1, D48.1, D49.1, D52.1, D53.1, D54.1, D55.1, D56.1, D57.1, D58.1, D59.1, D60.1, D61.1, D62.1, D63.1, D64.1, D65.1, D66.1, D67.1, D68.1, D69.1, D70.1, D71.1, D72.1, D73.1, D74.1, D75.1, D78.1, D79.1, D80.1, D81.1, D82.1, D83.1, D84.1, D85.1, D94.1, D96.1, D97.1, D98.1, D99.1, D100.1, D101.1, D102.1, D103.1, D104.1, J1.6, J2.6, J3.4, J4.6, J5.2, J5.3, J6.6, R4.1, R10.1, R15.1, R37.2, R38.2, R44.1, RN5.1, RN5.2, RN5.3, RN5.4, RN6.1, RN6.2, RN6.3, RN6.4, RN7.5, RN7.6, RN7.7, RN7.8, RN8.5, RN8.6, RN8.7, RN8.8, RN30.5, RN30.6, RN30.7, RV1.3, SW1.1, SW4.1, SW6.3, SW6.4, SW8.1, U1.8, U2.10, U3.8, U4.14, U4.20, U4.21, U4.22, U4.23, U4.24, U4.25, U5.3, U6.10, U7.8, U7.15, U8.8, U8.15, U9.1, U9.10, U10.1, U10.10, U10.19, U11.10, U12.7, U13.7, U14.10, U15.10, U16.10, U17.10, U18.3, U18.5, U18.21, U20.6, U20.18, U20.28, U20.39, U21.1, U21.10, U22.10, U23.10, U24.10, U25.10, U26.10, U27.1, U27.2, U27.7, U28.3, U29.3, U30.3, U30.4, U30.5, U30.6, U30.8, U31.10, U32.10, U33.1, U33.10, U33.11, U33.12, U33.13, U34.14, U34.20, U35.3, U36.3, U37.10, U38.14, U38.20, U39.3, U40.3, U41.10, U42.1, U42.2, U42.3, U42.4, U42.7, U43.6, U43.18, U43.28, U43.39, U44.14, U44.20, U45.3, U46.3, U47.10, U48.2, U49.3, U49.7, U49.9, U50.3, U51.3, U52.3, U53.4
unnamed: C12.1, U13.6
unnamed: C12.2, R9.2, R10.2
unnamed: C13.1, R13.1, U13.13
unnamed: C14.1, R14.1, SW5.1
unnamed: C58.1, R43.1, SW7.1
unnamed: C59.1, R46.2, U49.5
unnamed: D1.1, R2.2
unnamed: D2.1, R3.2
unnamed: D3.1, R4.2
unnamed: D4.2, RN1.4
unnamed: D5.2, RN1.3
unnamed: D6.2, RN1.2
unnamed: D7.2, RN1.1
unnamed: D8.2, RN2.4
unnamed: D9.2, RN2.3
unnamed: D10.2, RN2.2
unnamed: D11.2, RN2.1
unnamed: D12.2, R5.1
unnamed: D13.1, R6.2
unnamed: D14.2, R7.1
unnamed: D15.2, RN3.4
unnamed: D16.2, RN3.3
unnamed: D17.2, RN3.2
unnamed: D18.2, RN3.1
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

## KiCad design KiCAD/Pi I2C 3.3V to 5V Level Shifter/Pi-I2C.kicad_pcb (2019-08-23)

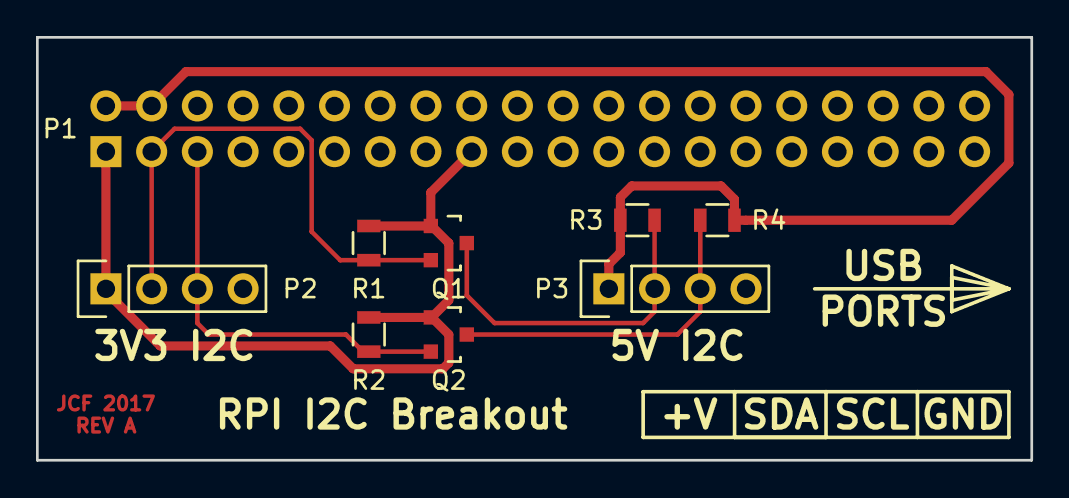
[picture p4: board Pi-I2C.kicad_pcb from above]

Board: 2 copper layers, 55.2 x 23.5 mm, 9 parts (1 on the bottom side), 7 nets.

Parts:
P1: CONN_01X40; Pin_Header_Straight_2x20
P2: I2C0 3V3; Pin_Header_Straight_1x04
P3: I2C1 5V; Pin_Header_Straight_1x04
Q1, Q2: BSS138; SOT-23
R1, R2: R; R_0805
R3, R4: 10k; R_0805

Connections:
+3V3: P1.1, P1.17, P2.1, Q1.1, Q2.1, R1.1, R2.1
+5V: P1.2, P1.4, P3.1, R3.1, R4.1
/SCL1: P1.5, P2.3, Q2.2, R2.2
/SCL1_5V: P3.3, Q2.3, R4.2
/SDA1: P1.3, P2.2, Q1.2, R1.2
/SDA1_5V: P3.2, Q1.3, R3.2
GND: P1.6, P1.9, P1.14, P1.20, P1.25, P1.30, P1.34, P1.39, P2.4, P3.4

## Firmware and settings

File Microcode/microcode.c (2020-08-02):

/* MIT License

Copyright (c) 2019 James French

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
THE SOFTWARE IS PROVIDED "AS IS", WITHOUT WARRANTY OF ANY KIND, EXPRESS OR
IMPLIED, INCLUDING BUT NOT LIMITED TO THE WARRANTIES OF MERCHANTABILITY,
FITNESS FOR A PARTICULAR PURPOSE AND NONINFRINGEMENT. IN NO EVENT SHALL THE
AUTHORS OR COPYRIGHT HOLDERS BE LIABLE FOR ANY CLAIM, DAMAGES OR OTHER
LIABILITY, WHETHER IN AN ACTION OF CONTRACT, TORT OR OTHERWISE, ARISING FROM,
OUT OF OR IN CONNECTION WITH THE SOFTWARE OR THE USE OR OTHER DEALINGS IN THE
SOFTWARE.
*/

#include <stdint.h>
#include <stdio.h>
#include <string.h>

// EEPROM 1
#define	CI      (1<<0)
#define	CO      (1<<1)
#define BO      (1<<2)
#define BI      (1<<3)
#define AL0     (1<<4)
#define AL1     (1<<5)
#define AL2     (1<<6)
#define AL3     (1<<7)

// EEPROM 2
#define ALO     (1<<8)
#define ALI     (1<<9)
#define RI      (1<<10)
#define RO      (1<<11)
#define MD      (1<<12)
#define MI      (1<<13)
#define SPO     (1<<14)
#define SPI     (1<<15)

//EEPROM 3
#define	AO      (1<<16)
#define	AI      (1<<17)
#define HLT     (1<<18)
#define PE      (1<<19)
#define PO      (1<<20)
#define PI      (1<<21)
#define MSR     (1<<22)
#define II      (1<<23)

// Inverted Signals
#define INVERT	(PI|PO|HLT|AI|AO|BI|BO|CI|CO|MI|RO|RI|ALO|ALI|SPO|SPI|MSR|II|MD)

// ALU
#define ALC(CMD)    ((uint32_t)CMD << 4)

// By making this 0000, I can remove a hardware register and just use the AVR
#define ALU_LAST    0b0000

// 74LS382 Compatibility
#define B_MINUS_A   0b0001
#define A_MINUS_B   0b0010
#define A_PLUS_B    0b0011
#define A_XOR_B     0b0100
#define A_OR_B      0b0101
#define A_AND_B     0b0110

// Additional functionality
#define HOLD        0b0000
#define A           0b0111
#define A_ZERO      0b1000
#define NOT_A       0b1001
#define INC_A       0b1010
#define DEC_A       0b1011
#define SHIFT_L     0b1100
#define SHIFT_R     0b1101
#define ADDC	    0b1110
#define SUBC	    0b1110

// Flags Addresses
#define CARRY_ADDR  (1 << 11)
#define FLAGS_ADDR  (1 << 12)

#define FLAGS_F0C0  0
#define FLAGS_F0C1  1
#define FLAGS_F1C0  2
#define FLAGS_F1C1  3

// Main Op Codes
#define MOV		    0b00
#define LOD		    0b01
#define STO		    0b10
#define ALU		    0b11

// Registers
#define	Ra		    0b000
#define Rb		    0b001
#define Rc		    0b010
#define Rd          0b011
#define SP		    0b100
#define PC	    	0b101
#define SPi		    0b110
#define IMM	    	0b111

#define OPCODE(op,dreg,sreg) (((op)<<6)|((dreg)<<3)|(sreg))
#define ALU_OPCODE(alc,sreg) ((ALU<<6)|((alc)<<2)|(sreg))

uint32_t UC_Template[256][8];

void populate_template(void) {
	for (int i = 0; i < 256; i++ ) {
		// All instructions start with this
		UC_Template[i][0] = MI|PO;
		UC_Template[i][1] = RO|II|PE;

		// Default instruction is to HALT
		UC_Template[i][2] = HLT;

		// Unused steps reset the step counter
		//UC_Template[i][2] = MSR;
		UC_Template[i][3] = MSR;
		UC_Template[i][4] = MSR;
		UC_Template[i][5] = MSR;
		UC_Template[i][6] = MSR;
		UC_Template[i][7] = MSR;
	}
}

// Read/Write Registers

uint32_t O(uint32_t reg) {

  switch (reg) {
	case Ra: return AO;
	case Rb: return BO;
	case Rc: return CO;
	case Rd: return SPO;
	case SP: return SPO;
	case PC: return PO;
	default: return 0;
  }
}

uint32_t I(uint8_t reg) {

  switch (reg) {
	case Ra: return AI;
	case Rb: return BI;
	case Rc: return CI;
	case Rd: return SPI;
	case SP: return SPI;
	case PC: return PI;
	default: return 0;
  }
}

uint32_t flip_inverted(uint32_t microcode_word) {
	microcode_word ^= INVERT;
	return microcode_word;
}


void write_MOV() {
	uint8_t opcode;
	for (int dreg = Ra; dreg <= PC; dreg++) {
		for(int sreg = Ra; sreg <= PC; sreg++) {
			if(sreg != dreg) {
				opcode = OPCODE(MOV, dreg, sreg);
				UC_Template[opcode][2] = O(sreg) | I(dreg) | MSR;
			}
		}

		// Move Immediate
		opcode = OPCODE(MOV, dreg, IMM);
		UC_Template[opcode][2] = PO | MI | PE;
		UC_Template[opcode][3] = RO | I(dreg) | MSR;
	}

	// NOP
	opcode = OPCODE(MOV, Ra, Ra);
	UC_Template[opcode][2] = MSR;

	// HLT  -   This is the actual Halt command. If every other opcode gains
	//          meaning then this will still be Halt.
	opcode = OPCODE(MOV, PC, PC);
	UC_Template[opcode][2] = HLT;
}


void write_LOD() {
	uint8_t opcode;
	for (int dreg = Ra; dreg <= PC; dreg++) {
		for (int sreg = Ra; sreg <= PC; sreg++) {
			opcode = OPCODE(LOD, dreg, sreg);
			UC_Template[opcode][2] = MI | O(sreg);
			UC_Template[opcode][3] = MD | RO | I(dreg) | MSR;
		}

		// Load Immediate
		opcode = OPCODE(LOD, dreg, IMM);
		UC_Template[opcode][2] = PO | MI | PE;
		UC_Template[opcode][3] = RO | MI;
		UC_Template[opcode][4] = RO | MD | I(dreg) | MSR;

		// POP Instructions
		opcode = OPCODE(LOD, dreg, SPi);
		UC_Template[opcode][2] = SPO | ALI;
		UC_Template[opcode][3] = SPI | MI | ALC(DEC_A) | ALO;
		UC_Template[opcode][4] = MD | RO | I(dreg) | MSR;
	}
}

void write_STO() {
	uint8_t opcode;
	for (int sreg = Ra; sreg <= PC; sreg++) {
		for (int dreg = Ra; dreg <= PC; dreg++) {
			opcode = OPCODE(STO, dreg, sreg);
			UC_Template[opcode][2] = MI | O(dreg);
			UC_Template[opcode][3] = RI | MD | O(sreg) | MSR;
		}

		// Store Immediate
		opcode = OPCODE(STO, IMM, sreg);
		UC_Template[opcode][2] = MI | PE | PO;
		UC_Template[opcode][3] = RO | MI;
		UC_Template[opcode][4] = RI | MD | O(sreg) | MSR;

		// PUSH Instructions
		opcode = OPCODE(STO, SPi, sreg);
		UC_Template[opcode][2] = MI | ALI | SPO;
		UC_Template[opcode][3] = RI | MD | O(sreg);
		UC_Template[opcode][4] = SPI | ALC(INC_A) | ALO | MSR;
	}
}

void write_ALU(void) {
	uint8_t opcode;

	for (uint8_t reg = Ra; reg <= Rd; reg++) {
		for (uint8_t alc = 0; alc < 16; alc++) {
			opcode = ALU_OPCODE(alc, reg);
			UC_Template[opcode][2] = O(reg) | ALI;
			UC_Template[opcode][3] = I(reg) | ALC(alc) | ALO | MSR;
		}
	}
}


uint8_t eeprom_shift(uint32_t data, uint8_t shift) {
	uint8_t out;

	out = (data >> 8*shift) & 0xff;
	return out;
}

int main(void) {
	populate_template();
	FILE *fp;

	write_MOV();
	write_STO();
	write_LOD();
	write_ALU();

	uint32_t ucode[4][256][8];
	uint8_t opcode;

	memcpy(ucode[FLAGS_F0C0], UC_Template, sizeof(UC_Template));
	memcpy(ucode[FLAGS_F0C1], UC_Template, sizeof(UC_Template));
	memcpy(ucode[FLAGS_F1C0], UC_Template, sizeof(UC_Template));
	memcpy(ucode[FLAGS_F1C1], UC_Template, sizeof(UC_Template));

	// Carry
	opcode = OPCODE(MOV, IMM, 0b0000);
	ucode[FLAGS_F0C0][opcode][2] = PE | MSR; // skip the next memory adress
	ucode[FLAGS_F1C0][opcode][2] = PE | MSR; // skip the next memory adress

	ucode[FLAGS_F0C1][opcode][2] = PO | MI | PE;
	ucode[FLAGS_F0C1][opcode][3] = RO | PI | MSR;

	ucode[FLAGS_F1C1][opcode][2] = PO | MI | PE;
	ucode[FLAGS_F1C1][opcode][3] = RO | PI | MSR;

	char buffer[10];

	// Flags
	for (uint8_t flag = 0; flag <= 2; flag++) {
		opcode = OPCODE(MOV, IMM, (1<<flag));
		ucode[FLAGS_F0C0][opcode][2] = PE | MSR; // skip the next memory adress
		ucode[FLAGS_F0C1][opcode][2] = PE | MSR; // skip the next memory adress

		ucode[FLAGS_F1C0][opcode][2] = PO | MI | PE;
		ucode[FLAGS_F1C0][opcode][3] = RO | PI | MSR;

		ucode[FLAGS_F1C1][opcode][2] = PO | MI | PE;
		ucode[FLAGS_F1C1][opcode][3] = RO | PI | MSR;
	}



	// flip bits
	for (int i = 0; i < 4; i++) {
		for (int j = 0; j < 256; j++) {
			for (int k = 0; k < 8; k++) {
				ucode[i][j][k] = flip_inverted(ucode[i][j][k]);
			}
		}
	}

	fp = fopen("microcode.bin", "w");

	uint8_t out[256];
	for (int ee = 0; ee < 3; ee++) {
		for (int flag = 0; flag < 4; flag++) {
			for (int step = 0; step<8; step++) {
				for (int opcode = 0; opcode <256; opcode++) {
					out[opcode] = eeprom_shift(ucode[flag][opcode][step], ee);
				}
				fwrite(out, sizeof(out[0]), sizeof(out)/sizeof(out[0]), fp);
			}
		}
	}
	return 0;
}

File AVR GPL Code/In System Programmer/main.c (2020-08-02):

/*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
 *  You should have received a copy of the GNU General Public License
 *  along with this program.  If not, see <https://www.gnu.org/licenses/>.
 */

#include <stdio.h>
#include <stdlib.h>
#include <avr/io.h>
#include <avr/interrupt.h>
#include <avr/sleep.h>
#include <i2cmaster.h>

#define _AE PC2
#define RW	PC3
#define	_AS	PC4
#define _BS	PC5
#define _CS PC6
#define _EE PC7

#define WR PB5

#define AT24C256	160

uint8_t data;

// sleeps 10ms
void sl(uint16_t us) {
	us--;
	cli();
	TCNT1 = 0;
	OCR1A = us;

	TCCR1B |= (1 << CS11);

	sei();

	sleep_enable();
	sleep_cpu();
	sleep_disable();

	cli();

	TCCR1B = 0;
}

void write(uint16_t addr, uint8_t data) {
	// Set Buffers to Write
	PORTC |= (1 << RW);

	// EEPROM addressing
	PORTD = addr & 255;
	PORTB = (addr >> 8);

	// Port A becomes an output
	DDRA = 0xff;
	PORTA = data;

	// Pulse the write pin, sleep for 10ms
	PORTB |= (1 << PB5);
	PORTB ^= (1 << PB5);
	sl(10000);

	// Port A back to an input
	DDRA = 0;
	PORTA = 0;

	// Set Buffers to Read
	PORTC &= ~(1 << RW);
}

uint8_t read(uint16_t addr) {
	uint8_t out;

	// Set buffers to read, enable EEPROM output
	PORTC &= ~((1 << RW)|(1 << _EE));

	// EEPROM addressing
	PORTD = addr & 255;
	PORTB = (addr >> 8);

	// 500us sleep for the dust to settle (can probably be shorter)
	sl(500);

	// Read the current EEPROM value
	out = PINA;

	// Disable the EEPROM output
	PORTC |= (1 << _EE);
	return out;
}

// Only required for software write protected EEPROMs
// These values match the EEPROM magic address & data
// values to the board address & data lines.

void unlock(void) {
	write(0x0d4d, 0x55);
	write(0x12b2, 0xaa);
	write(0x0d4d, 0x04);
	write(0x0d4d, 0x55);
	write(0x12b2, 0xaa);
	write(0x0d4d, 0x01);
}

void write_eeprom(uint8_t select) {
	uint16_t i;
	uint8_t data;
	uint8_t edata;

	PORTC &= ~(1 << select);

	i2c_start_wait(AT24C256+I2C_READ);
	for (i=0; i<8192; i++) {

		data = (i == 8191) ? i2c_readNak() : i2c_readAck();
		edata = read(i);

		if (edata != data) { write(i, data); }
	}
	i2c_stop();

	PORTC |= (1 << select);
}

int main(void) {
	i2c_init();

	// Last byte of the EEPROM
	i2c_start_wait(AT24C256+I2C_WRITE);
	i2c_write(0x7F);
	i2c_write(0xFF);
	i2c_stop();

	i2c_start_wait(AT24C256+I2C_READ);
	data = i2c_readNak();
	i2c_stop();

	// We've written this data before and are done.
	if(!data) {
		PORTC = (1 << _AS)|(1 << _BS)|(1 << _CS) ;
		DDRC = ((1 << _EE)|(1 << _AE)|(1 << RW))|(1 << _CS)|(1 << _BS)|(1 << _AS);
		set_sleep_mode(SLEEP_MODE_PWR_DOWN);
		sleep_enable();
		sleep_cpu();
	}

	PORTC = (0 << _AE) | (1 << _AS) | (1 << _BS) | (1 << _CS) | (0 << _EE);
	DDRC |= (1 << PC2) | (1 << PC3) | (1 << PC4);
	DDRC |= (1 << PC5) | (1 << PC6) | (1 << PC7);

	DDRB |= (1 << PB5);

	// Timer Setup
	TCCR1A |= (1<<WGM12); // CTC
	TCCR1B = 0;
	TIMSK |= (1 << OCIE1A);

	set_sleep_mode(SLEEP_MODE_IDLE);

	// Disable the Address Buffer
	PORTC |= (1 << _AE);

	DDRD = 255;
	DDRB |= 63;

	write_eeprom(_AS);
	write_eeprom(_BS);
	write_eeprom(_CS);

	// Last byte of the EEPROM
	i2c_start_wait(AT24C256+I2C_WRITE);
	i2c_write(0x7F);
	i2c_write(0xFF);
	i2c_write(0x00);
	i2c_stop();

	DDRD = 0;
	PORTD = 0;
	DDRB = DDRB & ~63;
	PORTB = PORTB & ~63;

	PORTC = (1 << _AS)|(1 << _BS)|(1 << _CS) ;
	DDRC = ((1 << _EE)|(1 << _AE)|(1 << RW))|(1 << _CS)|(1 << _BS)|(1 << _AS);

	set_sleep_mode(SLEEP_MODE_PWR_DOWN);
	sleep_enable();
	sleep_cpu();

	return 0; // never reached
}

EMPTY_INTERRUPT(TIMER1_COMPA_vect);

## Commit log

2019-08-23 8-Bit Computer Schematic Files,
    * Revision A - Untested Use at Own Risk
    * Pi I2C level shifter design
    [8-Bit CPU.sch, AVR_ALU.sch, AVR_Clock.sch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]
2019-09-01 Microcode for Rev A Board
    * Don't build the RevA board there are some issues!
    [microcode.c]
2019-09-02 KiCAD cleanup - Revision A
    Revision A Known Issues:
    * ATTiny45 has incorrect footprint
    * Flags register is redundant (The ATMega16's output port is a register)
    * Power jack pinout is wrong (12V shorted to ground)
    * Step counter reset logic is wrong (Active high signalling, Active low input)
    * ALU output indicator not connected
    * HLT indicator missing
    * EEPROMs can't be page written due to addressing setup (minor annoyance)
    * Flags Logic uses NAND gates instead of AND (fixed on the board I built)
    * Programmer needs to be able to toggle EEPROM outputs and Addressing Devices
    with different signals to enable reading.
    [8-Bit CPU.sch, AVR_ALU.sch, Clock.sch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]
2019-09-02 Deleted redundant schematic
    [Addr Register.sch]
2020-07-13 KiCAD files update & Gerbers
    [8-Bit CPU-B_Cu.gbl, 8-Bit CPU-B_Mask.gbs, 8-Bit CPU-B_SilkS.gbo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]
2020-07-13 Add arm.bin

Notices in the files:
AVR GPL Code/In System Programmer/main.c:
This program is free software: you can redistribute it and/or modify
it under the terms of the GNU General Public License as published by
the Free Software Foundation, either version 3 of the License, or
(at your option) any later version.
